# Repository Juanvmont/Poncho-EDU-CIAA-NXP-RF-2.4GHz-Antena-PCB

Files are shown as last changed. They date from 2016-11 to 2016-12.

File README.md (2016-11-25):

# Poncho-EDU-CIAA-NXP-RF-2.4GHz-Antena-PCB
Este circuito de poncho implementa una unidad de radio que opera en la banda de frecuencias abierta de 2.4GHz y compila con aplicaciones de la EDU-CIAA NXP que soportan el estándar IEEE 802.15.4: IEEE Standards Association. IEEE Standard for Local and metropolitan area networks–Part 15.4: Low-Rate Wireless Personal Area Networks (LR-WPANs) y ZIGBEE.

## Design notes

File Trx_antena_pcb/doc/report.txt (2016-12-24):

Info: Reading netlist file "/home/juanv/Desktop/MSE/diseñoPcb/tpfinal_Kicad/Trx_antena_pcb/Trx_antena_pcb.net".

Info: Using references to match components and footprints.

Error: Component 'U2' footprint 'QFN65P400X400X100-16N' was not found in any libraries in the footprint library table.

Error: Component 'U1' footprint 'QFN50P500X500X100-28N' was not found in any libraries in the footprint library table.

Info: Checking netlist component footprint "1uF/6.3V1:/582F8126/5834A0B8:Capacitors_SMD:C_0402".

Adding new component "1uF/6.3V1:/582F8126/5834A0B8" footprint "Capacitors_SMD:C_0402".

Changing component "1uF/6.3V1:/582F8126/5834A0B8" pin "1" net name from "" to "Net-(1uF/6.3V1-Pad1)".

Changing component "1uF/6.3V1:/582F8126/5834A0B8" pin "2" net name from "" to "GND".

Info: Checking netlist component footprint "A1:/582F8126/582F82E2:Wpan_Prints:INV_F_ANT".

Adding new component "A1:/582F8126/582F82E2" footprint "Wpan_Prints:INV_F_ANT".

Changing component "A1:/582F8126/582F82E2" pin "2" net name from "" to "GND".

Changing component "A1:/582F8126/582F82E2" pin "3" net name from "" to "GND".

Changing component "A1:/582F8126/582F82E2" pin "1" net name from "" to "Net-(A1-Pad1)".

Info: Checking netlist component footprint "C1:/582F8126/5834A314:Capacitors_SMD:C_0402".

Adding new component "C1:/582F8126/5834A314" footprint "Capacitors_SMD:C_0402".

Changing component "C1:/582F8126/5834A314" pin "1" net name from "" to "GND".

Changing component "C1:/582F8126/5834A314" pin "2" net name from "" to "Net-(C1-Pad2)".

Info: Checking netlist component footprint "C2:/582F8126/5834A3A6:Capacitors_SMD:C_0402".

Adding new component "C2:/582F8126/5834A3A6" footprint "Capacitors_SMD:C_0402".

Changing component "C2:/582F8126/5834A3A6" pin "1" net name from "" to "Net-(C2-Pad1)".

Changing component "C2:/582F8126/5834A3A6" pin "2" net name from "" to "GND".

Info: Checking netlist component footprint "C3:/582F8126/58349EA0:Capacitors_SMD:C_0402".

Adding new component "C3:/582F8126/58349EA0" footprint "Capacitors_SMD:C_0402".

Changing component "C3:/582F8126/58349EA0" pin "1" net name from "" to "GND".

Changing component "C3:/582F8126/58349EA0" pin "2" net name from "" to "Net-(1uF/6.3V1-Pad1)".

Info: Checking netlist component footprint "C4:/582F8126/5834877F:Capacitors_SMD:C_0402".

Adding new component "C4:/582F8126/5834877F" footprint "Capacitors_SMD:C_0402".

Changing component "C4:/582F8126/5834877F" pin "1" net name from "" to "GND".

Changing component "C4:/582F8126/5834877F" pin "2" net name from "" to "Net-(1uF/6.3V1-Pad1)".

Info: Checking netlist component footprint "C5:/582F8126/5834A030:Capacitors_SMD:C_0402".

Adding new component "C5:/582F8126/5834A030" footprint "Capacitors_SMD:C_0402".

Changing component "C5:/582F8126/5834A030" pin "1" net name from "" to "GND".

Changing component "C5:/582F8126/5834A030" pin "2" net name from "" to "Net-(1uF/6.3V1-Pad1)".

Info: Checking netlist component footprint "C6:/582F8126/5834A1E1:Capacitors_SMD:C_0402".

Adding new component "C6:/582F8126/5834A1E1" footprint "Capacitors_SMD:C_0402".

Changing component "C6:/582F8126/5834A1E1" pin "1" net name from "" to "Net-(C6-Pad1)".

Changing component "C6:/582F8126/5834A1E1" pin "2" net name from "" to "Net-(C6-Pad2)".

Info: Checking netlist component footprint "C7:/582F8126/5834B4E9:Capacitors_SMD:C_0402".

Adding new component "C7:/582F8126/5834B4E9" footprint "Capacitors_SMD:C_0402".

Changing component "C7:/582F8126/5834B4E9" pin "1" net name from "" to "Net-(C7-Pad1)".

Changing component "C7:/582F8126/5834B4E9" pin "2" net name from "" to "GND".

Info: Checking netlist component footprint "C8:/582F8126/5834A259:Capacitors_SMD:C_0402".

Adding new component "C8:/582F8126/5834A259" footprint "Capacitors_SMD:C_0402".

Changing component "C8:/582F8126/5834A259" pin "1" net name from "" to "Net-(C8-Pad1)".

Changing component "C8:/582F8126/5834A259" pin "2" net name from "" to "Net-(C8-Pad2)".

Info: Checking netlist component footprint "C9:/582F8126/584ED152:Capacitors_SMD:C_0402".

Adding new component "C9:/582F8126/584ED152" footprint "Capacitors_SMD:C_0402".

Changing component "C9:/582F8126/584ED152" pin "1" net name from "" to "/Radio/TL11".

Changing component "C9:/582F8126/584ED152" pin "2" net name from "" to "GND".

Info: Checking netlist component footprint "C10:/582F8126/5850220F:Capacitors_SMD:C_0402".

Adding new component "C10:/582F8126/5850220F" footprint "Capacitors_SMD:C_0402".

Changing component "C10:/582F8126/5850220F" pin "1" net name from "" to "GND".

Changing component "C10:/582F8126/5850220F" pin "2" net name from "" to "/Radio/TL11".

Info: Checking netlist component footprint "C11:/582F8126/584E9FD7:Capacitors_SMD:C_0402".

Adding new component "C11:/582F8126/584E9FD7" footprint "Capacitors_SMD:C_0402".

Changing component "C11:/582F8126/584E9FD7" pin "1" net name from "" to "GND".

Changing component "C11:/582F8126/584E9FD7" pin "2" net name from "" to "/Radio/TL11".

Info: Checking netlist component footprint "C12:/582F8126/583545EA:Capacitors_SMD:C_0402".

Adding new component "C12:/582F8126/583545EA" footprint "Capacitors_SMD:C_0402".

Changing component "C12:/582F8126/583545EA" pin "1" net name from "" to "GND".

Changing component "C12:/582F8126/583545EA" pin "2" net name from "" to "Net-(C12-Pad2)".

Info: Checking netlist component footprint "C13:/582F8126/58350D19:Capacitors_SMD:C_0402".

Adding new component "C13:/582F8126/58350D19" footprint "Capacitors_SMD:C_0402".

Changing component "C13:/582F8126/58350D19" pin "1" net name from "" to "Net-(C13-Pad1)".

Changing component "C13:/582F8126/58350D19" pin "2" net name from "" to "GND".

Info: Checking netlist component footprint "C14:/582F8126/584FC11B:Capacitors_SMD:C_0402".

Adding new component "C14:/582F8126/584FC11B" footprint "Capacitors_SMD:C_0402".

Changing component "C14:/582F8126/584FC11B" pin "1" net name from "" to "Net-(C14-Pad1)".

Changing component "C14:/582F8126/584FC11B" pin "2" net name from "" to "GND".

Info: Checking netlist component footprint "C15:/582F8126/58350FA6:Capacitors_SMD:C_0402".

Adding new component "C15:/582F8126/58350FA6" footprint "Capacitors_SMD:C_0402".

Changing component "C15:/582F8126/58350FA6" pin "1" net name from "" to "Net-(C13-Pad1)".

Changing component "C15:/582F8126/58350FA6" pin "2" net name from "" to "Net-(C15-Pad2)".

Info: Checking netlist component footprint "C16:/582F8126/583510DE:Capacitors_SMD:C_0402".

Adding new component "C16:/582F8126/583510DE" footprint "Capacitors_SMD:C_0402".

Changing component "C16:/582F8126/583510DE" pin "1" net name from "" to "Net-(C15-Pad2)".

Changing component "C16:/582F8126/583510DE" pin "2" net name from "" to "GND".

Info: Checking netlist component footprint "H1:/5613C419:Poncho_Modelos:Led_Hole".

Info: Checking netlist component footprint "H2:/5613C2CE:Poncho_Modelos:Led_Hole".

Info: Checking netlist component footprint "L1:/582F8126/58356107:Capacitors_SMD:C_0402".

Adding new component "L1:/582F8126/58356107" footprint "Capacitors_SMD:C_0402".

Changing component "L1:/582F8126/58356107" pin "1" net name from "" to "+5V".

Changing component "L1:/582F8126/58356107" pin "2" net name from "" to "Net-(1uF/6.3V1-Pad1)".

Info: Checking netlist component footprint "L2:/582F8126/58389C11:Capacitors_SMD:C_0402".

Adding new component "L2:/582F8126/58389C11" footprint "Capacitors_SMD:C_0402".

Changing component "L2:/582F8126/58389C11" pin "1" net name from "" to "GND".

Changing component "L2:/582F8126/58389C11" pin "2" net name from "" to "Net-(C6-Pad2)".

Info: Checking netlist component footprint "L3:/582F8126/5838AB71:Capacitors_SMD:C_0402".

Adding new component "L3:/582F8126/5838AB71" footprint "Capacitors_SMD:C_0402".

Changing component "L3:/582F8126/5838AB71" pin "1" net name from "" to "Net-(C8-Pad1)".

Changing component "L3:/582F8126/5838AB71" pin "2" net name from "" to "GND".

Info: Checking netlist component footprint "L4:/582F8126/584EBE83:Capacitors_SMD:C_0402".

Adding new component "L4:/582F8126/584EBE83" footprint "Capacitors_SMD:C_0402".

Changing component "L4:/582F8126/584EBE83" pin "1" net name from "" to "+5V".

Changing component "L4:/582F8126/584EBE83" pin "2" net name from "" to "/Radio/TL11".

Info: Checking netlist component footprint "L5:/582F8126/5838B199:Capacitors_SMD:C_0402".

Adding new component "L5:/582F8126/5838B199" footprint "Capacitors_SMD:C_0402".

Changing component "L5:/582F8126/5838B199" pin "1" net name from "" to "Net-(C6-Pad2)".

Changing component "L5:/582F8126/5838B199" pin "2" net name from "" to "Net-(L5-Pad2)".

Info: Checking netlist component footprint "L6:/582F8126/5838B294:Capacitors_SMD:C_0402".

Adding new component "L6:/582F8126/5838B294" footprint "Capacitors_SMD:C_0402".

Changing component "L6:/582F8126/5838B294" pin "1" net name from "" to "Net-(L6-Pad1)".

Changing component "L6:/582F8126/5838B294" pin "2" net name from "" to "Net-(C8-Pad1)".

Info: Checking netlist component footprint "L7:/582F8126/584F89CD:Capacitors_SMD:C_0402".

Adding new component "L7:/582F8126/584F89CD" footprint "Capacitors_SMD:C_0402".

Changing component "L7:/582F8126/584F89CD" pin "1" net name from "" to "/Radio/TL11".

Changing component "L7:/582F8126/584F89CD" pin "2" net name from "" to "/Radio/TL101".

Info: Checking netlist component footprint "L8:/582F8126/584FBC83:Capacitors_SMD:C_0402".

Adding new component "L8:/582F8126/584FBC83" footprint "Capacitors_SMD:C_0402".

Changing component "L8:/582F8126/584FBC83" pin "1" net name from "" to "/Radio/TL101".

Changing component "L8:/582F8126/584FBC83" pin "2" net name from "" to "Net-(C14-Pad1)".

Info: Checking netlist component footprint "L9:/582F8126/5838BEF5:Capacitors_SMD:C_0402".

Adding new component "L9:/582F8126/5838BEF5" footprint "Capacitors_SMD:C_0402".

Changing component "L9:/582F8126/5838BEF5" pin "1" net name from "" to "Net-(L9-Pad1)".

Changing component "L9:/582F8126/5838BEF5" pin "2" net name from "" to "Net-(C13-Pad1)".

Info: Checking netlist component footprint "L10:/582F8126/5838CCFA:Capacitors_SMD:C_0402".

Adding new component "L10:/582F8126/5838CCFA" footprint "Capacitors_SMD:C_0402".

Changing component "L10:/582F8126/5838CCFA" pin "1" net name from "" to "Net-(C15-Pad2)".

Changing component "L10:/582F8126/5838CCFA" pin "2" net name from "" to "GND".

Info: Checking netlist component footprint "R1:/582F8126/5834A0FA:Resistors_SMD:R_0402".

Adding new component "R1:/582F8126/5834A0FA" footprint "Resistors_SMD:R_0402".

Changing component "R1:/582F8126/5834A0FA" pin "1" net name from "" to "Net-(1uF/6.3V1-Pad1)".

Changing component "R1:/582F8126/5834A0FA" pin "2" net name from "" to "/Radio/VREG_EN".

Info: Checking netlist component footprint "R2:/582F8126/58349A84:Resistors_SMD:R_0402".

Adding new component "R2:/582F8126/58349A84" footprint "Resistors_SMD:R_0402".

Changing component "R2:/582F8126/58349A84" pin "1" net name from "" to "/Radio/SO".

Changing component "R2:/582F8126/58349A84" pin "2" net name from "" to "GND".

Info: Checking netlist component footprint "R3:/582F8126/5834A339:Resistors_SMD:R_0402".

Adding new component "R3:/582F8126/5834A339" footprint "Resistors_SMD:R_0402".

Changing component "R3:/582F8126/5834A339" pin "1" net name from "" to "GND".

Changing component "R3:/582F8126/5834A339" pin "2" net name from "" to "Net-(R3-Pad2)".

Info: Checking netlist component footprint "R4:/582F8126/584E0D86:Resistors_SMD:R_0402".

Adding new component "R4:/582F8126/584E0D86" footprint "Resistors_SMD:R_0402".

Changing component "R4:/582F8126/584E0D86" pin "1" net name from "" to "/Radio/PAEN".

Changing component "R4:/582F8126/584E0D86" pin "2" net name from "" to "/Radio/GPIO5".

Info: Checking netlist component footprint "R5:/582F8126/584E2523:Resistors_SMD:R_0402".

Adding new component "R5:/582F8126/584E2523" footprint "Resistors_SMD:R_0402".

Changing component "R5:/582F8126/584E2523" pin "1" net name from "" to "/Radio/EN".

Changing component "R5:/582F8126/584E2523" pin "2" net name from "" to "/Radio/GPIO4".

Info: Checking netlist component footprint "R6:/582F8126/584E28F5:Resistors_SMD:R_0402".

Adding new component "R6:/582F8126/584E28F5" footprint "Resistors_SMD:R_0402".

Changing component "R6:/582F8126/584E28F5" pin "1" net name from "" to "/Radio/HGM".

Changing component "R6:/582F8126/584E28F5" pin "2" net name from "" to "/Radio/GPIO3".

Info: Checking netlist component footprint "R7:/582F8126/584E29A9:Resistors_SMD:R_0402".

Adding new component "R7:/582F8126/584E29A9" footprint "Resistors_SMD:R_0402".

Changing component "R7:/582F8126/584E29A9" pin "1" net name from "" to "/Radio/HGM".

Changing component "R7:/582F8126/584E29A9" pin "2" net name from "" to "/Radio/GPIO6".

Info: Checking netlist component footprint "R8:/582F8126/584D6395:Resistors_SMD:R_0402".

Adding new component "R8:/582F8126/584D6395" footprint "Resistors_SMD:R_0402".

Changing component "R8:/582F8126/584D6395" pin "1" net name from "" to "/Radio/PAEN".

Changing component "R8:/582F8126/584D6395" pin "2" net name from "" to "GND".

Info: Checking netlist component footprint "R9:/582F8126/583540C5:Resistors_SMD:R_0402".

Adding new component "R9:/582F8126/583540C5" footprint "Resistors_SMD:R_0402".

Changing component "R9:/582F8126/583540C5" pin "1" net name from "" to "GND".

Changing component "R9:/582F8126/583540C5" pin "2" net name from "" to "Net-(R9-Pad2)".

Info: Checking netlist component footprint "R10:/582F8126/58352221:Resistors_SMD:R_0402".

Adding new component "R10:/582F8126/58352221" footprint "Resistors_SMD:R_0402".

Changing component "R10:/582F8126/58352221" pin "1" net name from "" to "Net-(A1-Pad1)".

Changing component "R10:/582F8126/58352221" pin "2" net name from "" to "Net-(C15-Pad2)".

Info: Checking netlist component footprint "U1:/582F8126/582F81D4:QFN50P500X500X100-28N".

Error: Cannot add new component "U1:/582F8126/582F81D4" due to missing footprint "QFN50P500X500X100-28N".

Info: Checking netlist component footprint "U2:/582F8126/5830EB9B:QFN65P400X400X100-16N".

Error: Cannot add new component "U2:/582F8126/5830EB9B" due to missing footprint "QFN65P400X400X100-16N".

Info: Checking netlist component footprint "X1:/582F8126/5834A86F:Crystals:Crystal_SMD_5032_4Pads".

Adding new component "X1:/582F8126/5834A86F" footprint "Crystals:Crystal_SMD_5032_4Pads".

Changing component "X1:/582F8126/5834A86F" pin "1" net name from "" to "Net-(C1-Pad2)".

Changing component "X1:/582F8126/5834A86F" pin "3" net name from "" to "Net-(C2-Pad1)".

Changing component "X1:/582F8126/5834A86F" pin "2" net name from "" to "GND".

Changing component "X1:/582F8126/5834A86F" pin "3" net name from "" to "Net-(C2-Pad1)".

Info: Checking netlist component footprint "XA1:/560E5596:Poncho_Esqueleto:Conn_Poncho_Izquierdo".

Changing component "XA1:/560E5596" pin "42" net name from "+5VP" to "+5V".

Changing component "XA1:/560E5596" pin "58" net name from "Net-(P1-Pad4)" to "/Radio/SO".

Changing component "XA1:/560E5596" pin "60" net name from "Net-(P1-Pad2)" to "/Radio/SCLK".

Changing component "XA1:/560E5596" pin "61" net name from "Net-(P1-Pad3)" to "/Radio/SI".

Changing component "XA1:/560E5596" pin "69" net name from "Net-(XA1-Pad69)" to "/Radio/GPIO0".

Changing component "XA1:/560E5596" pin "71" net name from "Net-(XA1-Pad71)" to "/Radio/GPIO2".

Changing component "XA1:/560E5596" pin "72" net name from "Net-(P2-Pad4)" to "/Radio/GPIO1".

Changing component "XA1:/560E5596" pin "73" net name from "Net-(XA1-Pad73)" to "/Radio/GPIO4".

Changing component "XA1:/560E5596" pin "74" net name from "Net-(P2-Pad3)" to "/Radio/GPIO3".

Changing component "XA1:/560E5596" pin "75" net name from "Net-(XA1-Pad75)" to "/Radio/GPIO6".

Changing component "XA1:/560E5596" pin "76" net name from "Net-(P2-Pad2)" to "/Radio/GPIO5".

Changing component "XA1:/560E5596" pin "78" net name from "Net-(XA1-Pad78)" to "/Radio/VREG_EN".

Changing component "XA1:/560E5596" pin "80" net name from "Net-(XA1-Pad80)" to "/Radio/RESET".

Error: Component 'X1' pad '4' not found in footprint 'Crystals:Crystal_SMD_5032_4Pads'

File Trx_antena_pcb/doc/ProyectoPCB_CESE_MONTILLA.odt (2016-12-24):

Curso de Diseño de PCBs - CESE

Hoja de presentación de proyecto

Nombre corto del proyecto:

Poncho EDU-CIAA-NXP RF 2.4GHz Antena PCB

Autor:

Juan Vicente Montilla Cabrera

Fecha de este documento:

02 Noviembre de 2016

Licencia:

BSD

Repositorio de trabajo:

https://completar

Este proyecto: https://github.com/Juanvmont/Poncho-EDU-CIAA-NXP-RF-2.4GHz-Antena-PCB.git

Proyectos abiertos Ponchos EDU-CIAA: https://github.com/brengi/Ponchos.git

Proyectos relacionados con la CIAA: https://github.com/brengi/HardwareCIAA.git

Proyectos abiertos del curso https://github.com/brengi/CESE-PCB.git

Descripción:

Este circuito de poncho implementa una unidad de radio que opera en la banda de frecuencias abierta de 2.4GHz y compila con aplicaciones de la EDU-CIAA NXP que soportan el estándar IEEE 802.15.4: IEEE Standards Association. IEEE Standard for Local and metropolitan area networks–Part 15.4: Low-Rate Wireless Personal Area Networks (LR-WPANs) y ZIGBEE.

Requisitos del profesor:

1. Licencia abierta (se tiene que poder publicar los archivos KiCad y la funcionalidad del circuito).
2. Utilizar Kicad 4.0.x.
3. Consolidar toda la documentación en forma organizada dentro del directorio de proyecto de KiCad.
4. Aplicar una licencia o aclarar el Copyright.
5. Considerar en cada caso, los aspectos vistos referente a documentación.
6. Realizar diseño jerárquico salvo en circuitos muy pequeños.
7. Siempre que sea posible, considerar para los diseños componentes que se consigan en el mercado local.
8. Se utilizará como proveedor de referencia a Mayer (para las reglas de diseño).
9. Indicar que tipo/calidad de placa se considera para el diseño, intentando siempre que sea posible, seleccionar la de menor costo.

Tareas y Alcance:

1. Búsqueda de esquemáticos de referencia.
  Se tomará como punto de partida los Reference Design y el diseño del módulo de RF del Ing. Pablo Ridolfi (LSE) incluidos en /doc.
2. Adaptaciones de esquemático.
  Se hacen las adaptaciones para construir un poncho para la EDU-CIAA partiendo de los templates del Proyecto CIAA (Diego Brengi – UNLaM).
3. Ingreso de esquemático a Kicad.
4. Revisión del esquemático por un tercero.
  El revisor designado es el Esp. Ing. Patricio Bos (FIUBA-CESE).
5. Cálculo de presupuesto y proveedores de componentes.
  Se genera con la herramienta KiCost.
6. Selección de footprints.
7. Ubicación de componentes.
8. Ruteo.

Enlaces:

IEEE Standards Association. IEEE Standard for Local and metropolitan area

networks–Part 15.4: Low-Rate Wireless Personal Area Networks (LR-WPANs).

https://standards.ieee.org/getieee802/download/802.15. 4-2011.pdf

www.digikey.com/videos/en/v/Low-Power-RF-Product-CC2520/1646379569001

http://www.digikey.com/videos/en/v/Low-Power-RF-Product-CC2591/1646384367001

Guía de Selección de Antena. Texas Instrument. http://www.ti.com/lit/an/swra161b/swra161b.pdf

Design Note DN0007: 2.4 GHz Inverted F Antenna http://www.ti.com/lit/an/swru120b/swru120b.pdf

Using CC2591 Front End with CC2520 http://www.ti.com/lit/an/swra229a/swra229a.pdf

Características de la Antena:

Ventajas de Antenas PCB:

• Muy bajo costo

• Buen rendimiento para > 868 MHz

• Tamaño pequeño a altas frecuencias

• Diseños estándars disponibles

Desventajas de Antenas PCB:

• Dificultad para diseñar PCB antenas pequeñas y eficientes para < 433 MHz

• Potencialmente de largo tamaño a bajas frecuencias

2.4 GHz Antena (DN0007): Inverted-F Antenna (IFA)

Esta antena tiene mas eficiencia y un ancho de banda mas amplio que otras similares. Si el area del PCB es suficiente para posicionar una IFA, entonces se recomienda para diseños de 2.4GHz por encima de otras soluciones disponibles.

Ganancia en plano XY: 1.1 dB

Ganancia en plano XZ: 3.3 dB

Ganancia en plano YZ: 1.6 dB

Ganancia máxima: +3.3 dB

Eficiencia típica: 80% (EB) 94% (SA)

Ancho de banda @ VSWR 2.0: 280 MHz

Dimensiones (mm): 26 x 8

Reflexión: < -15 dB (<10% de la potencia disponible para un ancho de banda de >300MHz)

Imágenes:

Como imágenes ilustrativas, se muestra un producto similar: “Diseño e implementación de un nodo compatible con 802.15.4 para redes inalámbricas de sensores” (P. Ridolfi, S. Scaglia, A. Lutenberg, P. Martos, F. Vargas).

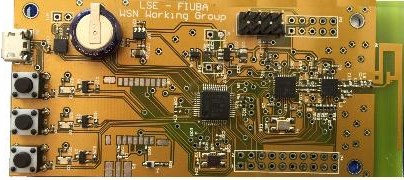
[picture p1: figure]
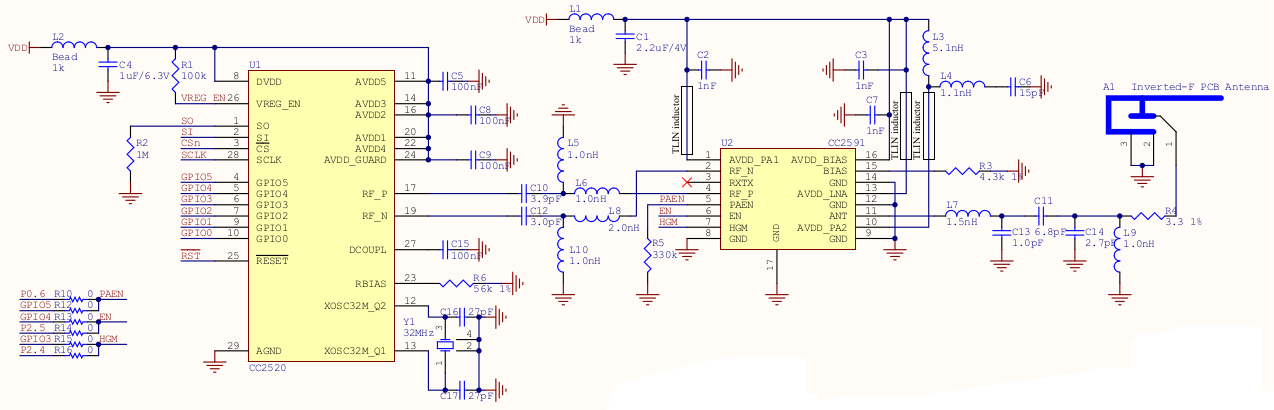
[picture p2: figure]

La adaptación corresponde a un circuito que sirve como poncho para la EDU-CIAA NXP. Para crearlo, se toma como base el template de Poncho Izquierdo. Realizado con la Version: (2015-08-26 BZR 6128)-product release de Kicad. Está ubicado en el siguiente directorio: https://github.com/brengi/Ponchos.git

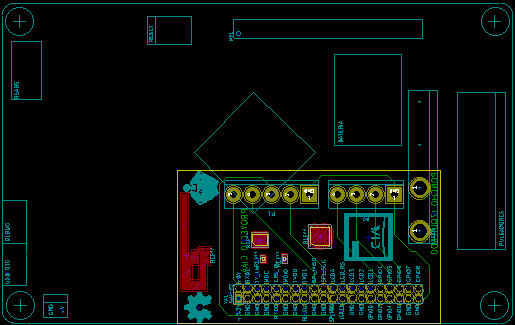
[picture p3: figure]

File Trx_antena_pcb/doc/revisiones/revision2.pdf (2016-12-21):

Juan Vicente Montilla Cabrera <juanvmontillac@gmail.com>

## CESE - PCB - TP FINAL - Revisión

Diego Brengi <diego.brengi@gmail.com> | 19 de diciembre de 2016, 22:49
Para: Juan Vicente Montilla Cabrera <juanvmontillac@gmail.com>

Hola:
Te mando una segunda revisión.
Lamentablemente veo que falta mucho del PCB y esta igual que la última vez que lo corregí. En pocos días ya haré la corrección final.

Saludos.

NOMBRE | | Juan Vicente Montilla Cabrera
EMAIL | | juanvmontillac@gmail.com
PROYECTO | | Antena PCB - Poncho
REPO | | https://github.com/Juanvmont/Poncho-EDU-CIAA-NXP-RF-2.4GHz-Antena-PCB.git
CORRECCION (Fecha) | | 18/12/16
Curso CESE - PCB | Docente | Diego Brengi
Documentación | Archivo hoja de proyecto en /doc | OK
| Archivos de revisiones en /doc | FALTAN
| Revisor designado | FALTA MECIONAR
Esquematico | Bibliotecas | Quitar todas las bibliotecas
| Rótulo | Agregar revisor. Se podría sacar la dirección de repo si falta un renglón.
| Jerarquía | Ok
| Campos KiCost | SI. Cuidado: C15 y C16 figuran como obsoletos en Digikey y se muestran los reemplazos.
| Prolijidad conexiones | OK
| Referencias | OK
| Comentarios | En la página principal, se ven los campos de footprint del conector. Colocar como invisibles.
| | Quitar los textos debajo de la URL del proyecto CIAA, son de ayuda para los templates, pero aquí ya no sirven.
| | En A1, colocar algún texto que de algo de información sobre que se trata de una antena, datos estimados de la misma, etc.
Gmail - CESE - PCB - TP FINAL - Revisión | https://mail.google.com/mail/u/0/?ui=2&ik=19...
1 of 2 | 21/12/16 14:44

Para facilidad de lectura, cablear las señales PAEN, EN y HGM. Se pueden dejar las etiquetas, pero aporta claridad si se dibujan las líneas de conexión en forma prolija.
ERC | OK
Asociación | Configuración bibliotecas

Bibliotecas con rutas absolutas: /home/juanv/Desktop/ubertoothmaster/ y /home/juanv/Desktop/Ej1/ juanvmont.Armar una biblioteca local dentro del proyecto con todos los footprints utilizados, y dejar solo esa como biblioteca activa.

PCB

Notas en PCB: Grila pos,
ruteo. Pista min, Vía min, aguj.
min, capas, terminación
superficial. | FALTA
Rótulo | OK
Encapsulados | INCOMPLETO
| INCOMPLETO
| INCOMPLETO
Borde del PCB | INCOMPLETO
Ancho de pistas | INCOMPLETO
DRC | INCOMPLETO
Ruteo | INCOMPLETO
| INCOMPLETO
| INCOMPLETO
| INCOMPLETO
Fiduciales | INCOMPLETO
Placement | INCOMPLETO
Serigrafía | INCOMPLETO
| INCOMPLETO
Textos en cobre o en
serigrafía, logos | INCOMPLETO
| INCOMPLETO
Dimensiones | INCOMPLETO
Fijación | INCOMPLETO
Belleza/Alineación | INCOMPLETO
Vista 3D | INCOMPLETO
Areas de cobre | INCOMPLETO
Gmail - CESE - PCB - TP FINAL - Revisión | https://mail.google.com/mail/u/0/?ui=2&ik=19...
2 of 2 | 21/12/16 14:44

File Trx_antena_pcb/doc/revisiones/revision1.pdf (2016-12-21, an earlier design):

Juan Vicente Montilla Cabrera <juanvmontillac@gmail.com>

## ProyectoPCB_CESE_MONTILLA

Diego Brengi <diego.brengi@gmail.com> | 30 de noviembre de 2016, 21:10
Para: Juan Vicente Montilla Cabrera <juanvmontillac@gmail.com>

Hola:
Te mando una primera corrección (parcial).
Saludos.
NOMBRE | | Juan Vicente Montilla Cabrera
EMAIL | | juanvmontillac@gmail.com
PROYECTO | | Antena PCB - Poncho
REPO | | https://github.com/Juanvmont/Poncho-EDU-CIAA-NXP-RF-2.4GHz-Antena-PCB.git
CORRECCION (Fecha) | | 30/11/16
Documentación | Archivo hoja de proyecto en /doc | Fuera de doc, en el raíz.
| Archivos de revisiones en /doc | Todavía no.
| Revisor designado | ???
Esquematico | Bibliotecas | Quitar las bibliotecas
| Rótulo | ORIGINAL SIN EDITAR
| Jerarquía | Hoja conectores vacía (borrar si no se utiliza)
| Campos KiCost | SI
| Prolijidad conexiones | Faltan terminar
| Referencias | INCOMPLETAS
| Cometarios | Licencia mal aplicada.
| | Que son estos archivos cc2591.SchLib y cc2591.PcbLib? si son cosas de altium colocarlo en un subdirectorio junto con una nota para saber de que se trata y porqué esta ahí.
| | Archivo gitignore debe borrarse, el que funciona es el que comienza con . (.gitignore)
| ERC | NO. Falta numerar. Cosas desconectadas.
Asociación | Configuración bibliotecas | Bibliotecas con rutas absolutas: /home/juanv/Desktop/ubertooth-master/ y /home/juanv/Desktop/Ej1/ juanvmont.Armar una biblioteca local dentro del proyecto con todos los footprints utilizados, y dejar solo esa
Gmail - ProyectoPCB_CESE_MONTILLA | https://mail.google.com/mail/u/0/?ui=2&ik=19...
1 of 2 | 21/12/16 14:38

como biblioteca activa.

PCB

Notas en PCB: Grila pos,
ruteo. Pista min, Vía min, aguj.
min, capas, terminación
superficial. | FALTA
Rótulo | FALTA
Encapsulados

Borde del PCB
Ancho de pistas
DRC
Ruteo

Fiduciales
Placement
Serigrafía

Dimensiones
Fijación
Belleza/Alineación
Vista 3D

Areas de cobre

[El texto citado está oculto]

Gmail - ProyectoPCB_CESE_MONTILLA | https://mail.google.com/mail/u/0/?ui=2&ik=19...
2 of 2 | 21/12/16 14:38

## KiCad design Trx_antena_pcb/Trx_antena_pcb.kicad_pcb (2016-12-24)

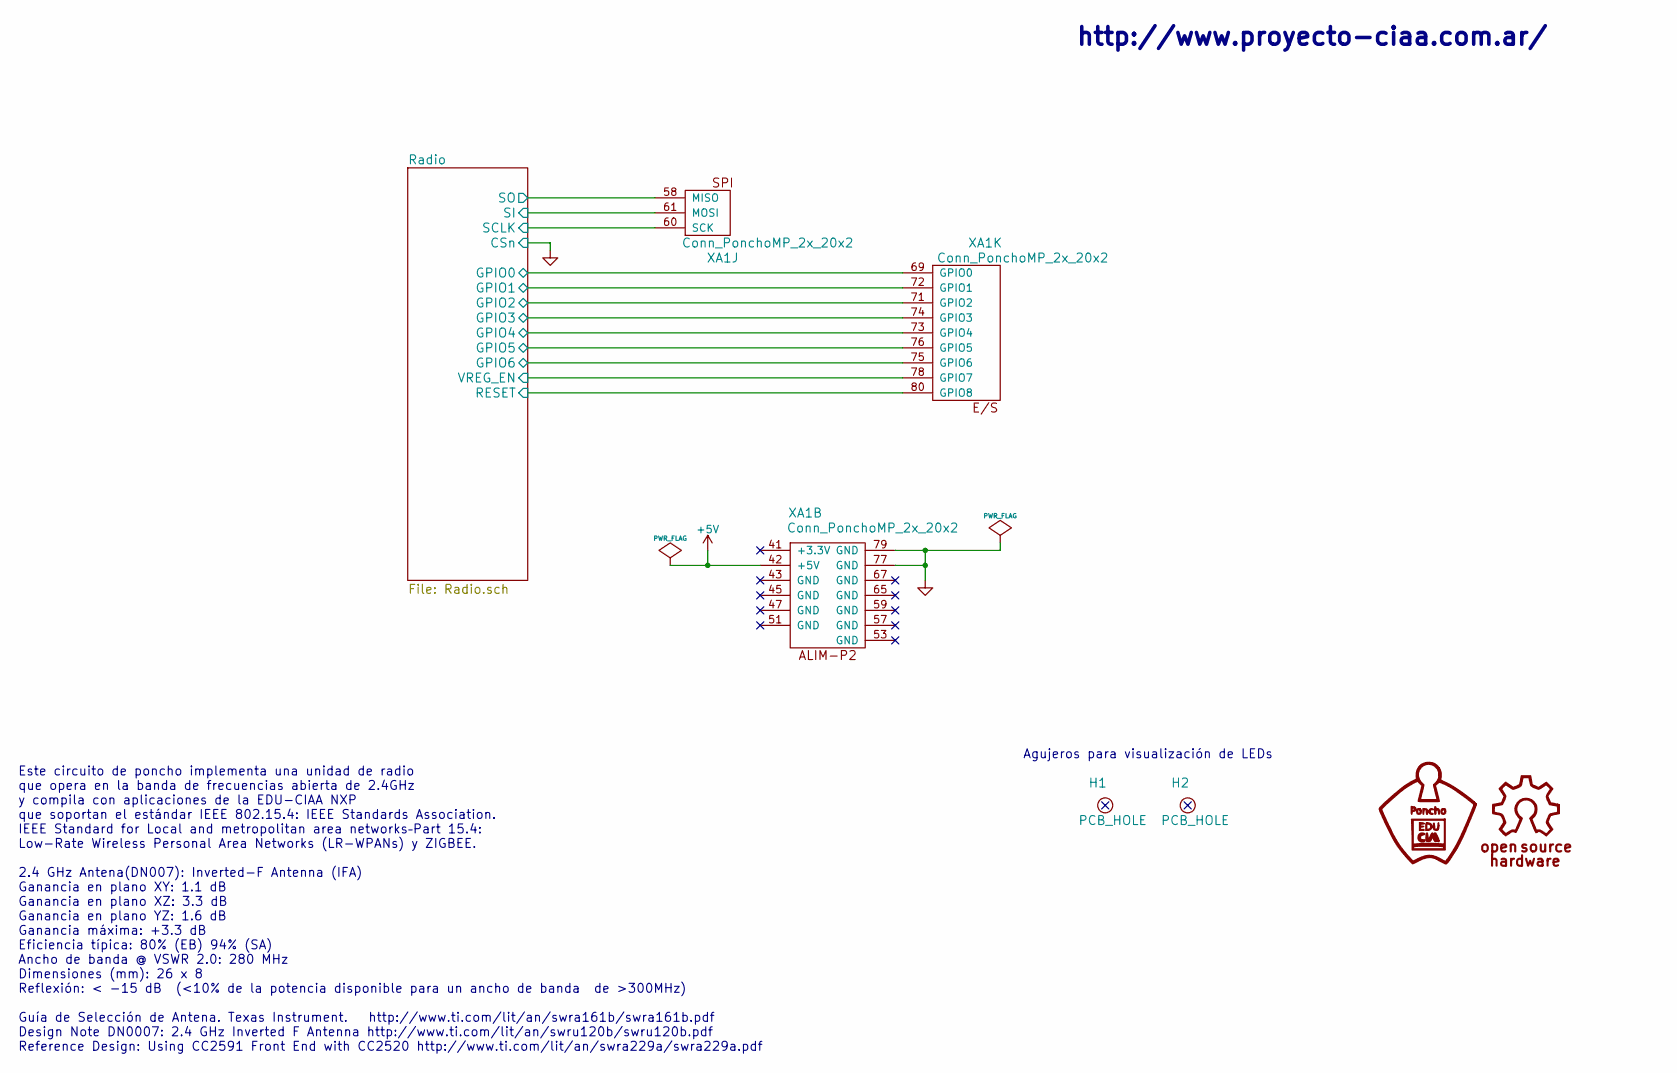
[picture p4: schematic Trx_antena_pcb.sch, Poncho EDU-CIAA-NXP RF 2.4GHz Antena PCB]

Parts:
H1, H2: PCB_HOLE; Led_Hole
XA1: Conn_PonchoMP_2x_20x2; Conn_Poncho_Izquierdo

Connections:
+5V: XA1.42 (+5V); also elsewhere on the board
/Radio/GPIO0: XA1.69 (GPIO0); also elsewhere on the board
/Radio/GPIO1: XA1.72 (GPIO1); also elsewhere on the board
/Radio/GPIO2: XA1.71 (GPIO2); also elsewhere on the board
/Radio/GPIO3: XA1.74 (GPIO3); also elsewhere on the board
/Radio/GPIO4: XA1.73 (GPIO4); also elsewhere on the board
/Radio/GPIO5: XA1.76 (GPIO5); also elsewhere on the board
/Radio/GPIO6: XA1.75 (GPIO6); also elsewhere on the board
/Radio/RESET: XA1.80 (GPIO8); also elsewhere on the board
/Radio/SCLK: XA1.60 (SCK); also elsewhere on the board
/Radio/SI: XA1.61 (MOSI); also elsewhere on the board
/Radio/SO: XA1.58 (MISO); also elsewhere on the board
/Radio/VREG_EN: XA1.78 (GPIO7); also elsewhere on the board
GND: XA1.77 (GND), XA1.79 (GND); also elsewhere on the board

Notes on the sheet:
http://www.proyecto-ciaa.com.ar/
Agujeros para visualización de LEDs
Este circuito de poncho implementa una unidad de radio que opera en la banda de frecuencias abierta de 2.4GHz y compila con aplicaciones de la EDU-CIAA NXP que soportan el estándar IEEE 802.15.4: IEEE Standards Association. IEEE Standard for Local and metropolitan area networks–Part 15.4: Low-Rate 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

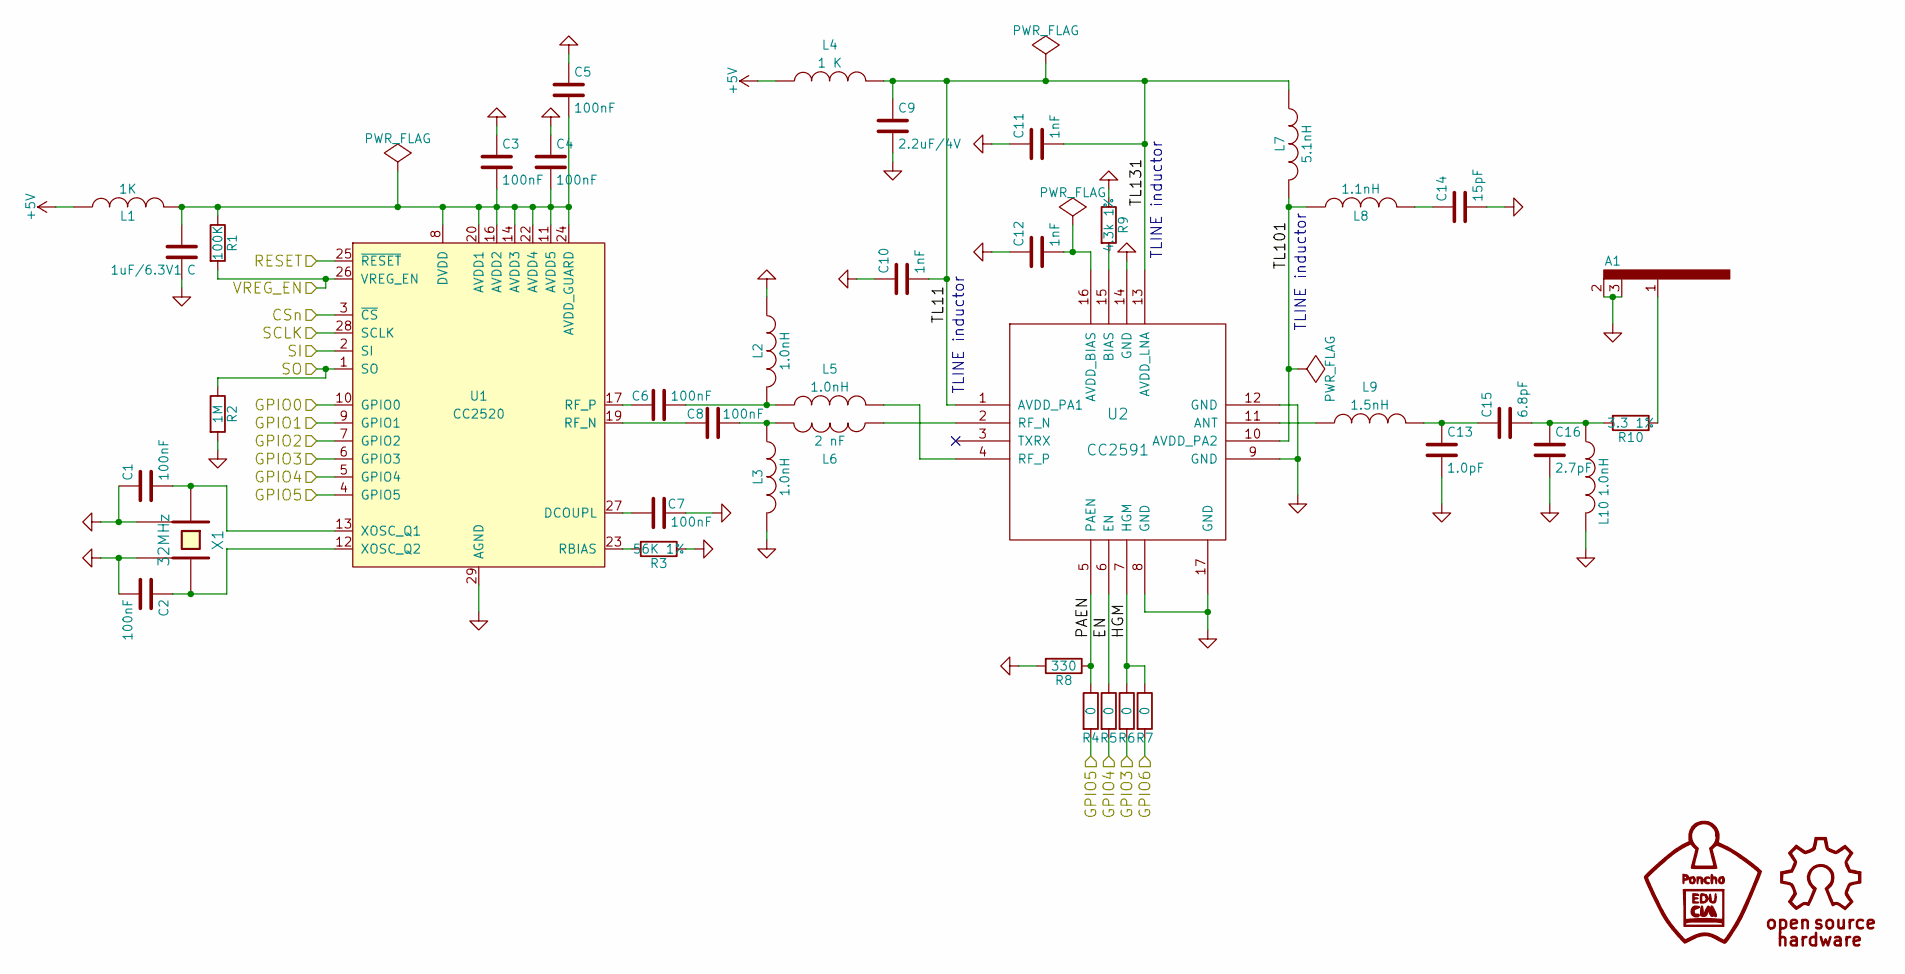
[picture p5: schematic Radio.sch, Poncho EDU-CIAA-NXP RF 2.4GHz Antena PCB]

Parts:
1uF/6.3V1: C; C_0402; Digikey# 490-3890-1-ND
A1: INV_F_ANT
C1, C2, C3, C4, C5, C6, C7, C8: 100nF; C_0402; Digikey# 311-1047-1-ND
C9: 2.2uF/4V; C_0402; Digikey# 445-3882-1-ND
C10, C11, C12: 1nF; C_0402; Digikey# 311-1036-1-ND
C13: 1.0pF; C_0402; Digikey# 490-3199-1-ND
C14: 15pF; C_0402; Digikey# 311-1017-1-ND
C15: 6.8pF; C_0402; Digikey# 490-5950-1-ND
C16: 2.7pF; C_0402; Digikey# 490-5934-1-ND
L1: 1K; C_0402; Digikey# 240-2555-1-ND
L2, L3, L5, L10: 1.0nH; C_0402; Digikey# 445-3035-1-ND
L4: 1 K; C_0402; Digikey# 240-2555-1-ND
L6: 2 nF; C_0402; Digikey# 445-3042-1-ND
L7: 5.1nH; C_0402; Digikey# 445-6360-1-ND
L8: 1.1nH; C_0402; Digikey# 445-6352-1-ND
L9: 1.5nH; C_0402; Digikey# 535-11505-1-ND
R1: 100K; R_0402; Digikey# RMCF0402JT1M00CT-ND
R2: 1M; R_0402; Digikey# RMCF0402JT1M00CT-ND
R3: 56K 1%; R_0402; Digikey# 311-56.0KLRCT-ND
R4, R5, R6, R7: 0; R_0402; Digikey# RMCF0402ZT0R00CT-ND
R8: 330; R_0402; Digikey# 311-330JRCT-ND
R9: 4.3k 1%; R_0402; Digikey# 311-4.30KLRCT-ND
R10: 3.3 1%; R_0402; Digikey# 311-3.30LRCT-ND
U1: CC2520; QFN-28-1EP_5x5mm_Pitch0.5mm; Digikey# 296-22996-1-ND
U2: CC2591; DFN-16-1EP_3x4mm_Pitch0.45mm; Digikey# 296-25327-1-ND
X1: 32MHz; Crystal_SMD_5032_4Pads; Digikey# 887-1312-1-ND

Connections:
+5V: L1.1, L4.1; also elsewhere on the board
/Radio/EN: R5.1, U2.6 (EN)
/Radio/GPIO0: U1.10 (GPIO0); also elsewhere on the board
/Radio/GPIO1: U1.9 (GPIO1); also elsewhere on the board
/Radio/GPIO2: U1.7 (GPIO2); also elsewhere on the board
/Radio/GPIO3: R6.2, U1.6 (GPIO3); also elsewhere on the board
/Radio/GPIO4: R5.2, U1.5 (GPIO4); also elsewhere on the board
/Radio/GPIO5: R4.2, U1.4 (GPIO5); also elsewhere on the board
/Radio/GPIO6: R7.2; also elsewhere on the board
/Radio/HGM: R6.1, R7.1, U2.7 (HGM)
/Radio/PAEN: R4.1, R8.1, U2.5 (PAEN)
/Radio/RESET: U1.25 (~RESET); also elsewhere on the board
/Radio/SCLK: U1.28 (SCLK); also elsewhere on the board
/Radio/SI: U1.2 (SI); also elsewhere on the board
/Radio/SO: R2.1, U1.1 (SO); also elsewhere on the board
/Radio/TL11: C9.1, C10.2, C11.2, L4.2, L7.1, U2.1 (AVDD_PA1), U2.13 (AVDD_LNA)
/Radio/TL101: L7.2, L8.1, U2.10 (AVDD_PA2)
/Radio/VREG_EN: R1.2, U1.26 (VREG_EN); also elsewhere on the board
GND: 1uF/6.3V1.2, A1.2, A1.3, C1.1, C2.2, C3.1, C4.1, C5.1, C7.2, C9.2, C10.1, C11.1, C12.1, C13.2, C14.2, C16.2, L2.1, L3.2, L10.2, R2.2, R3.1, R8.2, R9.1, U1.3 (~CS), U1.29 (AGND), U2.8 (GND), U2.9 (GND), U2.12 (GND), U2.14 (GND), U2.17 (GND), X1.2, X1.4; also elsewhere on the board
unnamed: 1uF/6.3V1.1, C3.2, C4.2, C5.2, L1.2, R1.1, U1.8 (DVDD), U1.11 (AVDD5), U1.14 (AVDD3), U1.16 (AVDD2), U1.20 (AVDD1), U1.22 (AVDD4), U1.24 (AVDD_GUARD)
unnamed: A1.1, R10.1
unnamed: C1.2, U1.13 (XOSC_Q1), X1.1
unnamed: C2.1, U1.12 (XOSC_Q2), X1.3
unnamed: C6.1, U1.17 (RF_P)
unnamed: C6.2, L2.2, L5.1
unnamed: C7.1, U1.27 (DCOUPL)
unnamed: C8.1, L3.1, L6.2
unnamed: C8.2, U1.19 (RF_N)
unnamed: C12.2, U2.16 (AVDD_BIAS)
unnamed: C13.1, C15.1, L9.2
unnamed: C14.1, L8.2
unnamed: C15.2, C16.1, L10.1, R10.2
unnamed: L5.2, U2.4 (RF_P)
unnamed: L6.1, U2.2 (RF_N)
unnamed: L9.1, U2.11 (ANT)
unnamed: R3.2, U1.23 (RBIAS)
unnamed: R9.2, U2.15 (BIAS)

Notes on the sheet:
TLINE inductor

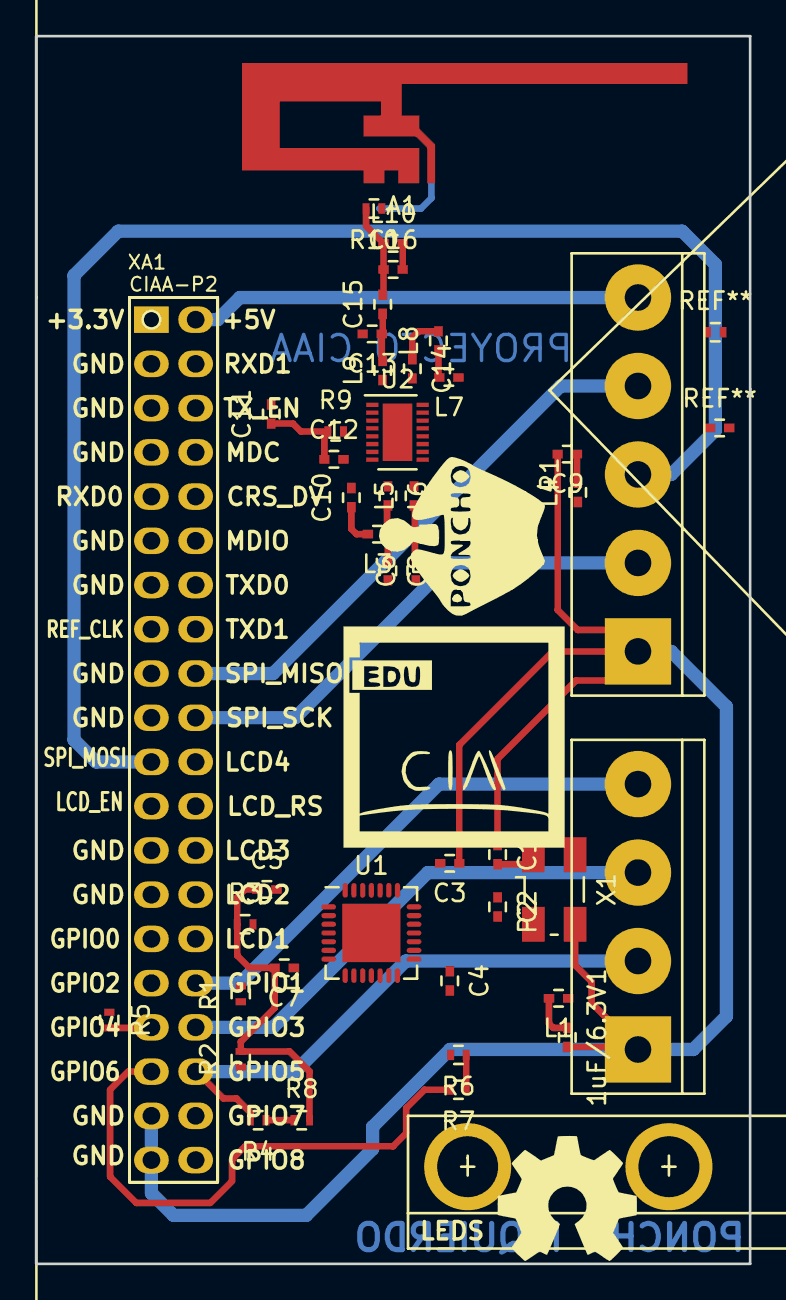
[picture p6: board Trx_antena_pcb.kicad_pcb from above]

Board: 2 copper layers, 41.0 x 70.5 mm, 48 parts (0 on the bottom side), 37 nets.

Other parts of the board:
G101: Logo_OSHWA
MP1: Plantilla_EDU-CIAA
P1: CONN_5; bornier5
P2: CONN_4; bornier4

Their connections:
GND: P1.1, P2.1; also elsewhere on the board

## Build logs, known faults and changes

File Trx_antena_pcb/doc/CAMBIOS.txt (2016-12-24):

Historial de cambios realizados 
================================

* Fecha: 30/11/16
* Autores: Juan Vicente Montilla
* Archivos: 
* Descripción: Curso de Diseño de PCBs - CESE

               <<Primeras correcciones: 30/11/16
-Completado del rotulo
-Archivo de hoja de proyecto movido a /doc y completado
-Creacion de archivo de revisiones en /doc
-Asignacion de revisor designado
-Corrección de gitignore duplicado
-Se quitan las bibliotecas no utilizadas
-Se define la jerarquia del circuito
->>

               <<Segundas correcciones: 02/12/16
-Correccion del rotulo
-Layout-Review-Techniques by TI en /doc
-Correccion de Licencia
->>

               <<Terceras correcciones: 12/12/16
-Completado esquematico
->>

               <<Cuartas correcciones: 21/12/16
-Archivos de revisiones en /doc
-Mension a revisor designado en rotulo
-Footprint de conectores invisibles
-Se borra textos de ayuda
-Se agrega informacion del circuito y la antena en A1
-Se cablean seniales PAEN, EN y HGM
-Se cambian sustitutos directos en componentes obsoletos
->>

               <<Quintas correcciones: 23/12/16
-Asignacion de footprints
-Generacion de Netlist
-Layout de componentes en PCBNEW segun reference design
->>

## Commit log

2016-11-25 Adding the project and documentation
    [Conectores.sch, Radio.sch, Trx_antena_pcb.kicad_pcb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]
2016-11-25 actualizando el .odt del proyecto
2016-12-04 "Segundas correcciones. Documentacion"
    [Conectores.sch, Radio.sch, Trx_antena_pcb.kicad_pcb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]
2016-12-10 Completando esquematico de RF
    [Radio.sch, Trx_antena_pcb.sch]
2016-12-12 mattching pin tou from edu ciaa to poncho
    [Radio.sch, Trx_antena_pcb.sch]
2016-12-13 completando el esquematico
    [Radio.sch, Trx_antena_pcb.sch]
2016-12-21 cuarta correccion: revision2 en /doc
    [Radio.sch, Trx_antena_pcb.sch]
2016-12-24 layout de componentes en pcbnew
    [Radio.sch, Trx_antena_pcb.kicad_pcb, Trx_antena_pcb.sch]
